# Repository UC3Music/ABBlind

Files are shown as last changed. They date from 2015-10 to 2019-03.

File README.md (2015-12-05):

ABBlind
--------------------------

Device to make random blind tests to audio equipment.

<p align="center">
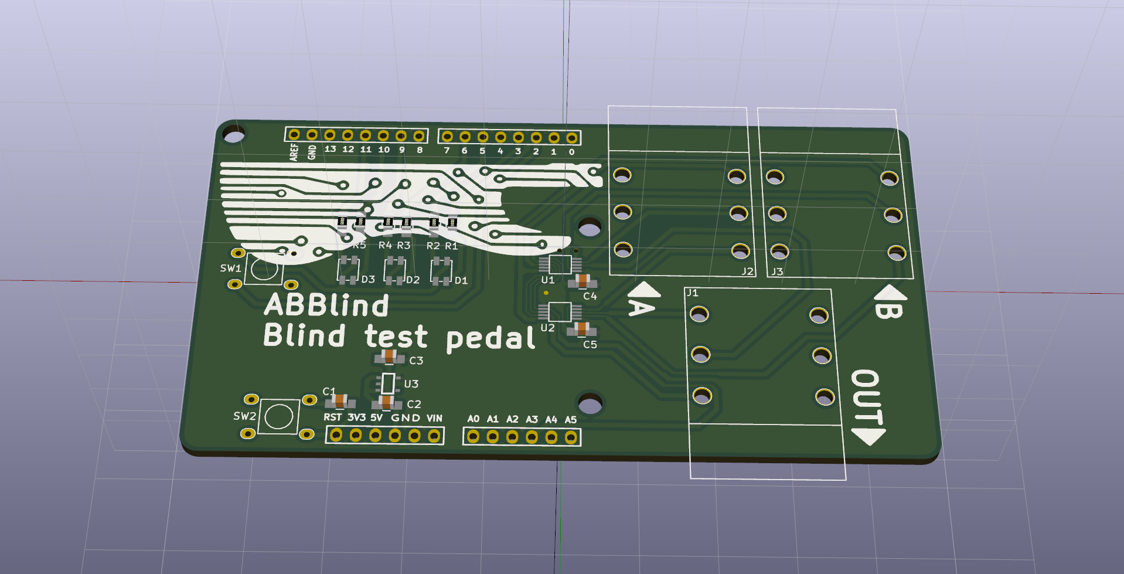
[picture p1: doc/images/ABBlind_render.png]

</p>

Why to spend lots of money in audiophile quality devices when you cannot tell the different from a more affordable device? ABBlind allows you to make blind tests for you to try to distinguish between two audio devices. It will randomly present you channels A and B, without telling you which channel are you listening to until you have heard three samples. Then, it will tell you in which order you listened to devices A and B.

As it is based on Arduino, you can modify ABBlind to add custom testing modes and more functionality.

## v0.1 Prototype
### Assembled

<p align="center">
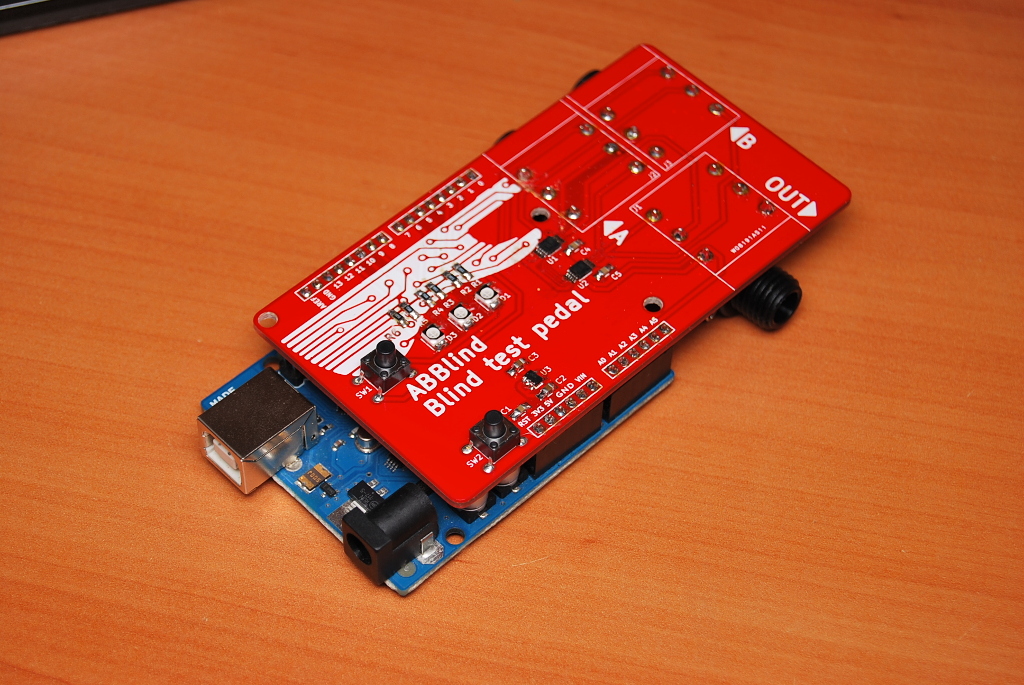
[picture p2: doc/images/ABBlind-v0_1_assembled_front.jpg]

</p>

<p align="center">
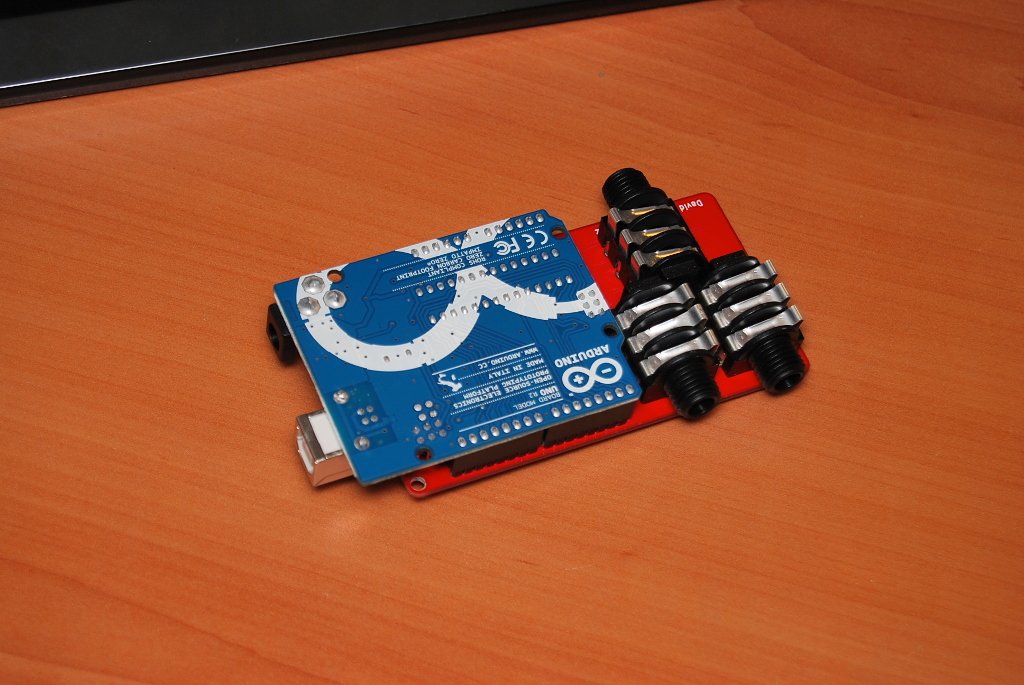
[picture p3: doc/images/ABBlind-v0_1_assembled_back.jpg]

</p>

### PCBs

<p align="center">
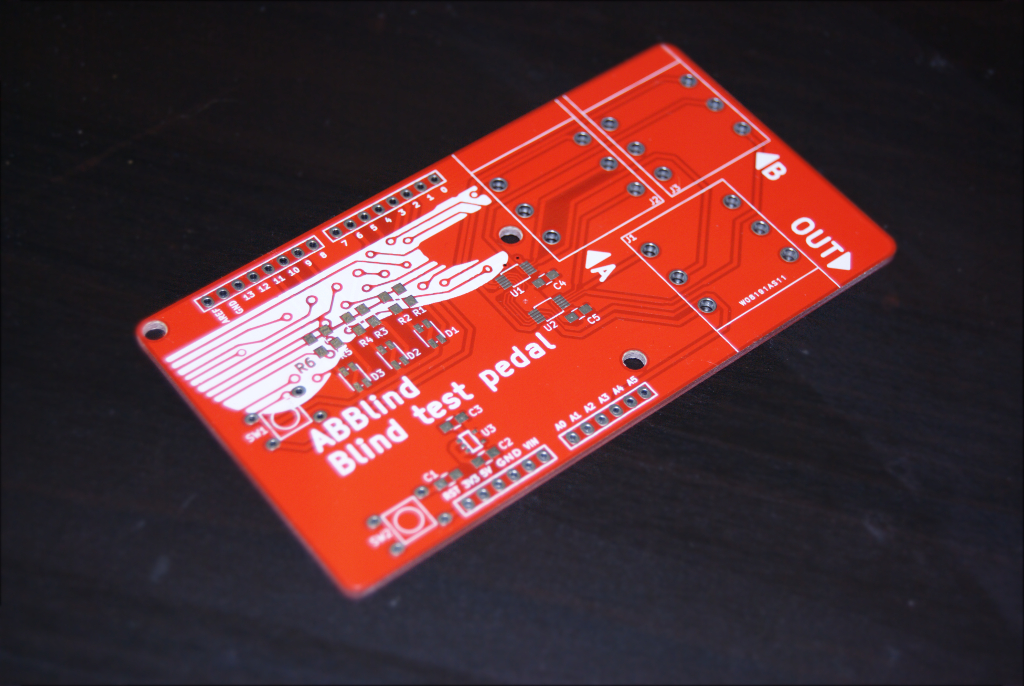
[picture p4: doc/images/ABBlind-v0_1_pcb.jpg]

</p>

## Firmware
### mbed version
Sources available at: https://developer.mbed.org/users/def/code/ABBlind_hardware_test/
# Credits
* Author: [David Estevez Fernandez](https://github.com/David-Estevez)

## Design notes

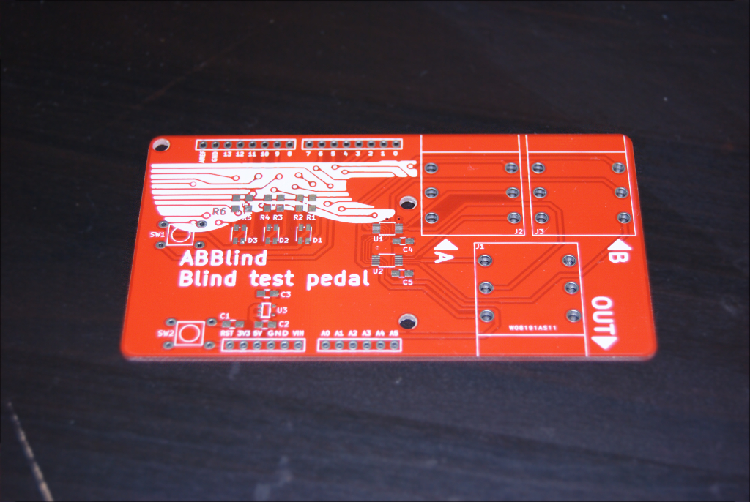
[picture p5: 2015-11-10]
doc/images/ABBlind-v0_1_pcb_front.jpg

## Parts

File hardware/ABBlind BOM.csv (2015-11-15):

Component | Amount | Reference | Seller | Unit Cost | Cost
Jack Female 6.35mm THD | 3 | 568-NYS219 | Mouser | 0.724 | 2.172
TS5A22364 | 2 | - | - | 0 | 0 | (samples)
Capacitor 0805 ceramic 100nF | 4 | 80-C0805C104K3R | Mouser | 0.091 | 0.364
Capacitor 0805 ceramic 1uF | 1 | 81-GRM219R61A105KA1D | Mouser | 0.109 | 0.109
Regulator TLV70033DDCR | 1 | 595-TLV70033DDCR | Mouser | 0.52€ | 0.52€
LED Bicolor 3528 | 3 | 859-LTST-E682KRKGWT | Mouser | 0.343 | 1.029
Resistor 0805 150R | 6 | 71-CRCW0805-150-E3 | Mouser | 0.091 | 0.546
Push switch | 2 | 506-2-1437565-8 | Mouser | 0.139 | 0.278
 |  |  |  | total: | 5.014

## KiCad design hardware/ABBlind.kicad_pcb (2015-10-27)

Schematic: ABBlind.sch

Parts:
BRD1: ARDUINO_UNO
C1: C; C_0805_HandSoldering
C2: 0.1-1uF X5R; C_0805_HandSoldering
C3: 1uF X5R; C_0805_HandSoldering
C4, C5: 0.1uF; C_0805_HandSoldering
D1, D2, D3: LED_BICOLOR
J1, J2, J3: JACK_FEMALE_STEREO_6_PINS; Conn_Jack_Female_635_THD
R1, R2, R3, R4, R5, R6: R; R_0805_HandSoldering
SW1, SW2: SW_PUSH; Switches-Push_switch_THD
U1, U2: TS5A22364
U3: TLV70033DDCT; SOT-23-5

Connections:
+3V3: C3.2, C4.2, C5.2, U1.1 (VCC), U2.1 (VCC), U3.5 (Vout)
+5V: BRD1.26 (5V), C2.2, U3.1 (Vin), U3.3 (EN)
/AUDIO_CNTRL: BRD1.19 (A3), U1.5 (IN), U1.7 (IN), U2.5 (IN), U2.7 (IN)
/FOOTSWITCH: BRD1.3 (2), SW1.2
/GND_A: J2.S, U1.8 (NC), U2.8 (NC)
/GND_B: J3.S, U1.10 (NO), U2.10 (NO)
/GND_OUT: J1.S, U1.9 (COM), U2.9 (COM)
/LED_1_1: BRD1.4 (3(PWM)), R1.1
/LED_1_2: BRD1.6 (5(PWM)), R2.1
/LED_2_1: BRD1.7 (6(PWM)), R3.1
/LED_2_2: BRD1.10 (9(PWM)), R4.1
/LED_3_1: BRD1.11 (10(PWM-SS)), R5.1
/LED_3_2: BRD1.12 (11(PWM-MOSI)), R6.1
/LEFT_A: J2.T, U2.4 (NC)
/LEFT_B: J3.T, U2.2 (NO)
/LEFT_OUT: J1.T, U2.3 (COM)
/RIGHT_A: J2.R, U1.4 (NC)
/RIGHT_B: J3.R, U1.2 (NO)
/RIGHT_OUT: J1.R, U1.3 (COM)
/~RESET: BRD1.28 (~RESET), C1.1, SW2.1
GND: BRD1.15 (GND), BRD1.24 (GND), BRD1.25 (GND), C1.2, C2.1, C3.1, C4.1, C5.1, D1.1 (K), D1.3 (K), D2.1 (K), D2.3 (K), D3.1 (K), D3.3 (K), SW1.1, SW2.2, U1.6 (GND), U2.6 (GND), U3.2 (GND)
unnamed: D1.2 (A), R2.2
unnamed: D1.4 (A), R1.2
unnamed: D2.2 (A), R4.2
unnamed: D2.4 (A), R3.2
unnamed: D3.2 (A), R6.2
unnamed: D3.4 (A), R5.2

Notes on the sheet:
INPUT A
INPUT B
OUTPUT
TI recommeds a 0.1uF bypass cap near supply

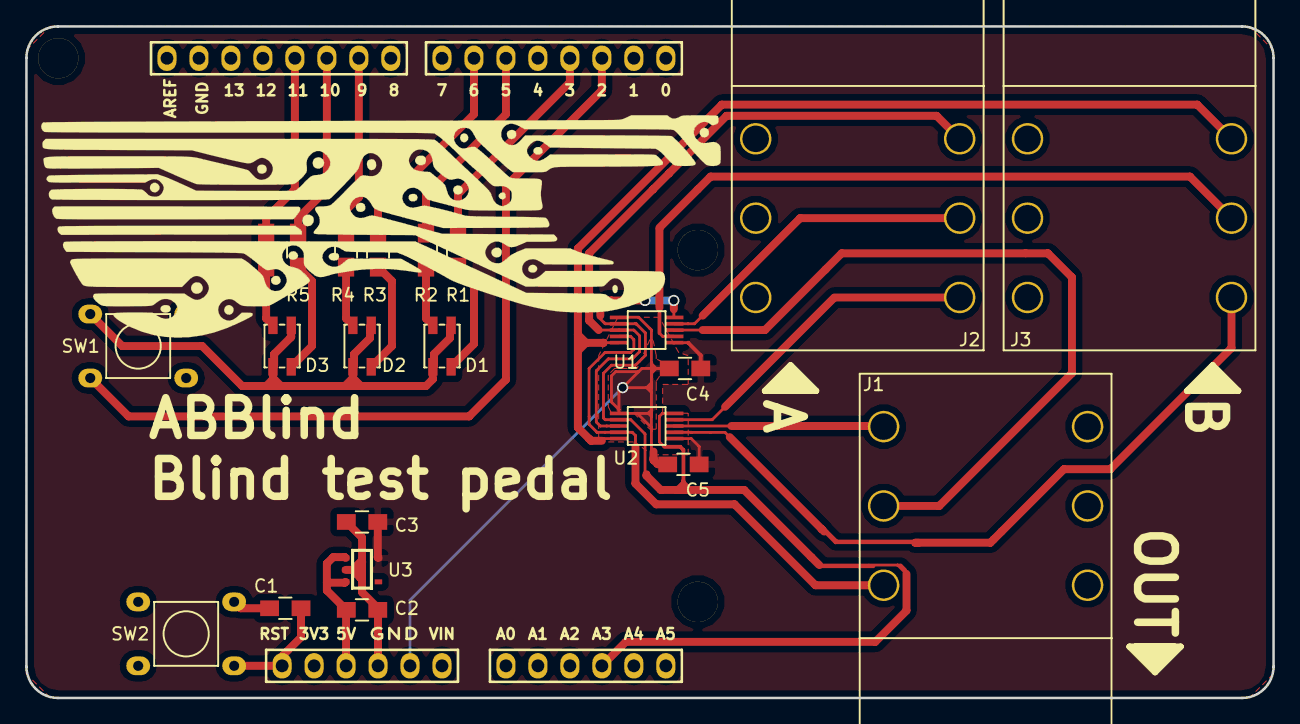
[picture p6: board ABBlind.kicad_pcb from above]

Board: 2 copper layers, 99.1 x 53.3 mm, 23 parts (0 on the bottom side), 27 nets.

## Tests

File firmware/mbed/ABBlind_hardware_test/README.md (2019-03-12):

Hardware Test firmware - mbed
-----------

This is a copy of the mbed sources that are also shared in the [mbed developer site](https://developer.mbed.org/users/def/code/ABBlind_hardware_test/).

This code requires the [PinDetect library](http://developer.mbed.org/users/xeta05/code/PinDetect/#cb6051b90a52).

# Programming Seeeduino Arch on Windows, Linux or Mac

Seeeduino Arch doesn't have an mbed interface. It uses USB In-System-Programming(ISP) to upgrade the firmware.

To enter the USB ISP mode, connect the Arch with your computer and long press its button, and then a disk named "CRP DISABLD" will appear.

* On windows

  1.  delete firmware.bin in the "CRP DISABLD" disk.
  2.  copy a new firmware into the disk.

* On linux

    1. if the disk is not mounted, mount the disk at {mnt_dir}
    2. Run:

            dd if={new_firmware.bin} of={mnt_dir}/firmware.bin conv=notrunc

* On mac you'll need to use Terminal to run the following script to copy you're .bin file to your Arch

        dd if={new_firmare.bin} of=/Volumes/CRP\ DISABLD/firmware.bin conv=notrunc

    If you're so inclined, you can also create an Automator application to support drag-and-drop of the file to your board. Just create a "Run Shell Script" with the following command:

        dd if=$* of=/Volumes/CRP\ DISABLD/firmware.bin conv=notrunc

    You will also need to change the "Pass Input" option from "to stdin" to "as arguments"--without this you will get an error "The action 'Run Shell Script' encountered an error" or "dd: no value specified for if (1)" in the log. 
    Also, an improved form of the script is:

        dd if="${1}" of=/Volumes/CRP\ DISABLD/firmware.bin conv=notrunc

    Which should handle spaces in the file path and only uses the first file supplied.

Very quick press the button to run the new firmware.

Source: http://www.seeedstudio.com/wiki/Seeeduino_Arch

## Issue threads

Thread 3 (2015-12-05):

Bidirectional design

David-Estevez, 2015-12-05:
Make the design bidirectional.

Maybe using these optocouplers/solid state relays: TLP172A(F)

David-Estevez, 2015-12-08:
Current Analog Switch has been tested and it seems to be already bidirectional

Closed 2015-12-08.

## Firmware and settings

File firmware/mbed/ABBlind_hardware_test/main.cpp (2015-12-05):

/**********************************************************
 * ABBlind test
 **********************************************************
 *
 * Program to test that all the hardware works correctly
 * 
 **********************************************************
 * Author: David Estévez Fernández (DEF)
 * License: GPLv3
 * 
 * A UC3Music project! Check out our website: 
 *         http://uc3music.github.io/
 */
#include "mbed.h"
#include "PinDetect.h"


//-- Peripherals definition
DigitalOut LED_01[] = {P1_24, P1_17}; 
DigitalOut LED_02[] = {P1_27, P1_25}; 
DigitalOut LED_03[] = {P0_9, P0_2};
DigitalOut AUDIO_SWITCH(P0_14);
PinDetect PUSH_BUTTON(P0_17, PullUp);

//-- Other constant definitions
static const uint8_t COLOR1 = 0;
static const uint8_t COLOR2 = 1;


//-- Other definitions
volatile uint8_t state = 0;

void start_sequence(uint16_t ms = 200)
{
  DigitalOut* leds[] = {&LED_01[0], &LED_02[0],
                        &LED_03[0], &LED_01[1], 
                        &LED_02[1], &LED_03[1]};
                    
  for (uint8_t i = 0; i < 6; i++)
  {
    for (uint8_t j = 0; j < 6; j++)
    {
      i == j ? *leds[j] = 1 : *leds[j] = 0;
    }
    wait_ms(ms);
  }
}

void button_pressed()
{
  state = (state+1) % 4;
}


int main() {
    
    //-- Setup button
    PUSH_BUTTON.attach_asserted(&button_pressed);
    PUSH_BUTTON.setSampleFrequency();
    
    //- Setup audio switch
    AUDIO_SWITCH = 0;
    
    start_sequence();
    start_sequence();
  
    while(1) {
     if (state == 0)
      {
        LED_01[0] = 0;
        LED_02[0] = 0;
        LED_03[0] = 0;
        LED_01[1] = 0;
        LED_02[1] = 0;
        LED_03[1] = 0;
        AUDIO_SWITCH = 0;
      }
      else if (state == 1)
      {
        LED_01[0] = 1;
        LED_02[0] = 1;
        LED_03[0] = 1;
        LED_01[1] = 0;
        LED_02[1] = 0;
        LED_03[1] = 0;
        AUDIO_SWITCH = 1;
      }
      else if (state == 2)
      {
        LED_01[0] = 0;
        LED_02[0] = 0;
        LED_03[0] = 0;
        LED_01[1] = 1;
        LED_02[1] = 1;
        LED_03[1] = 1;
        AUDIO_SWITCH = 0;
      }
      else if (state == 3)
      {
        LED_01[0] = 1;
        LED_02[0] = 1;
        LED_03[0] = 1;
        LED_01[1] = 1;
        LED_02[1] = 1;
        LED_03[1] = 1;
        AUDIO_SWITCH = 1;
      }
    
      wait_ms(500);
    }
}

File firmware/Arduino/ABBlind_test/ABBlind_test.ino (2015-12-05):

/**********************************************************
 * ABBlind test
 **********************************************************
 *
 * Program to test that all the hardware works correctly
 * 
 **********************************************************
 * Author: David Estévez Fernández (DEF)
 * License: GPLv3
 * 
 * A UC3Music project! Check out our website: 
 *         http://uc3music.github.io/
 */


//-- Hardware definitions
static const uint8_t LED_01[2] =  {5,  3};
static const uint8_t LED_02[2] =  {9,  6};
static const uint8_t LED_03[2] = {11, 10};

static const uint8_t PUSH_BUTTON = 2;

static const uint8_t AUDIO_SWITCH = A3;

//-- Other constant definitions
static const uint8_t COLOR1 = 0;
static const uint8_t COLOR2 = 1;


//-- Other definitions
volatile uint8_t state = 0;

void start_sequence(uint16_t ms = 200)
{
  uint8_t leds[] = {LED_01[0], LED_02[0],
                    LED_03[0], LED_01[1], 
                    LED_02[1], LED_03[1]};

  for (uint8_t i = 0; i < 6; i++)
  {
    for (uint8_t j = 0; j < 6; j++)
    {
      i == j ? digitalWrite(leds[j], HIGH) : digitalWrite(leds[j], LOW);
    }
    delay(ms);
  }
}
    
void button_pressed()
{
  state = (state+1) % 4;
}

void setup() 
{
  //-- Setup LEDs
  for (uint8_t i = 0; i < 2; i++)
  {
    pinMode(LED_01[i], OUTPUT);
    pinMode(LED_02[i], OUTPUT);
    pinMode(LED_03[i], OUTPUT);
  }

  //-- Setup button
  pinMode(PUSH_BUTTON, INPUT_PULLUP);
  attachInterrupt(digitalPinToInterrupt(PUSH_BUTTON), button_pressed, RISING);

  //- Setup audio switch
  pinMode(AUDIO_SWITCH, OUTPUT);
  digitalWrite(AUDIO_SWITCH, LOW);
  
  start_sequence();
  start_sequence();
}

void loop() 
{
  if (state == 0)
  {
    digitalWrite(LED_01[0], LOW);
    digitalWrite(LED_02[0], LOW);
    digitalWrite(LED_03[0], LOW);
    digitalWrite(LED_01[1], LOW);
    digitalWrite(LED_02[1], LOW);
    digitalWrite(LED_03[1], LOW);
    digitalWrite(AUDIO_SWITCH, LOW);
  }
  else if (state == 1)
  {
    digitalWrite(LED_01[0], HIGH);
    digitalWrite(LED_02[0], HIGH);
    digitalWrite(LED_03[0], HIGH);
    digitalWrite(LED_01[1], LOW);
    digitalWrite(LED_02[1], LOW);
    digitalWrite(LED_03[1], LOW);
    digitalWrite(AUDIO_SWITCH, HIGH);
  }
  else if (state == 2)
  {
    digitalWrite(LED_01[0], LOW);
    digitalWrite(LED_02[0], LOW);
    digitalWrite(LED_03[0], LOW);
    digitalWrite(LED_01[1], HIGH);
    digitalWrite(LED_02[1], HIGH);
    digitalWrite(LED_03[1], HIGH);
    digitalWrite(AUDIO_SWITCH, LOW);
  }
  else if (state == 3)
  {
    digitalWrite(LED_01[0], HIGH);
    digitalWrite(LED_02[0], HIGH);
    digitalWrite(LED_03[0], HIGH);
    digitalWrite(LED_01[1], HIGH);
    digitalWrite(LED_02[1], HIGH);
    digitalWrite(LED_03[1], HIGH);
    digitalWrite(AUDIO_SWITCH, HIGH);
  }

  delay(500);

}

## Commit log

2015-07-18 Add analog switch module
2015-07-23 Add hammond box CAD files
    [Hammond 1550B.fcstd]
2015-08-09 Finished v0.1 schematic
    [ABBlind.sch, Hammond 1550B.fcstd]
2015-08-11 Add footprint and symbol for LED bicolor
    [ABBlind.sch]
2015-08-16 Started working on the PCB
    [ABBlind.kicad_pcb, ABBlind.sch]
2015-08-18 Routing almost finished
    [ABBlind.kicad_pcb]
2015-08-19 Finish PCB routing
    [ABBlind.kicad_pcb]
2015-08-31 Round edges
    [ABBlind.kicad_pcb]
2015-08-31 Prototype 1 - v0.1
    [ABBlind.kicad_pcb]
2015-10-27 Pre-fabrication v1.0
    [ABBlind.kicad_pcb]
2015-10-27 Add gerber files
    [ABBlind.DRL, ABBlind.GBL, ABBlind.GBO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]
2015-11-04 Add BOM file
    [ABBlind BOM.csv]
2015-11-10 Move files to hardware
    [ABBlind BOM.csv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]
2015-11-15 Fix BOM
    [ABBlind BOM.csv]
2015-11-30 Add code to switch audio
2015-11-30 Add images of prototype
2015-12-05 Move Arduino files
